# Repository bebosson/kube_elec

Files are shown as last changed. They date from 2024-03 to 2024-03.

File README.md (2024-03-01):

# Le Kube (School Electronic Project) 
Implementation of an IoT solution for growing plants.\
Development of the Bill of Materials (BOM), Specification Document, and PCB Fabrication. \
Electrical schematics, circuit design, and component soldering. \
Firmware development in C for Atmega328p and ESP328p microcontrollers, along with an Adafruit screen. \
Implementation of UART, SPI, and I2C protocols, AT command usage, EEPROM memory handling, timers, and interrupts. \
LAMP stack setup on Raspberry Pi with JavaScript and MySQL solutions. \
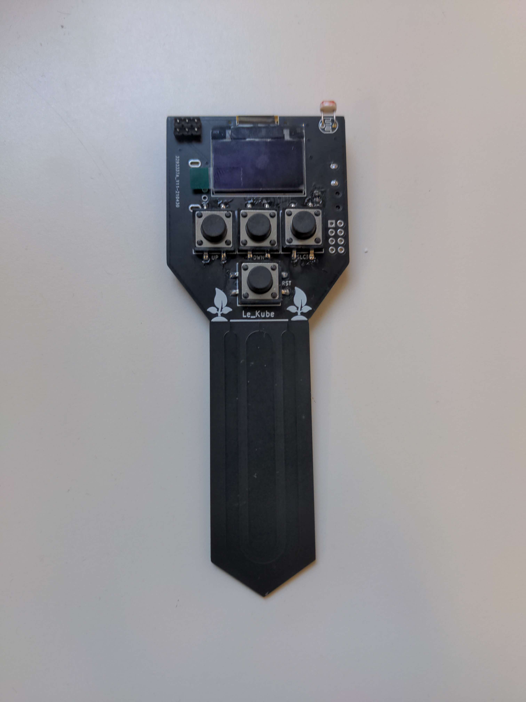
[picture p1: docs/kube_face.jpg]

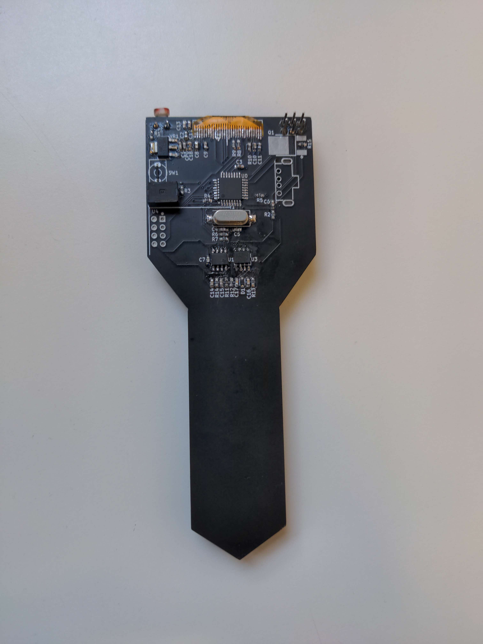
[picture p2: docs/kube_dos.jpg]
\
The data collected by the sensors are sent via wifi and accessible online, as well as on the Oled screen.
Variables monitored by the captors:
* `soil moisture
* `light
* `temperature
A water pump is connected to an optocoupler to automate the watering.

## Block diagram
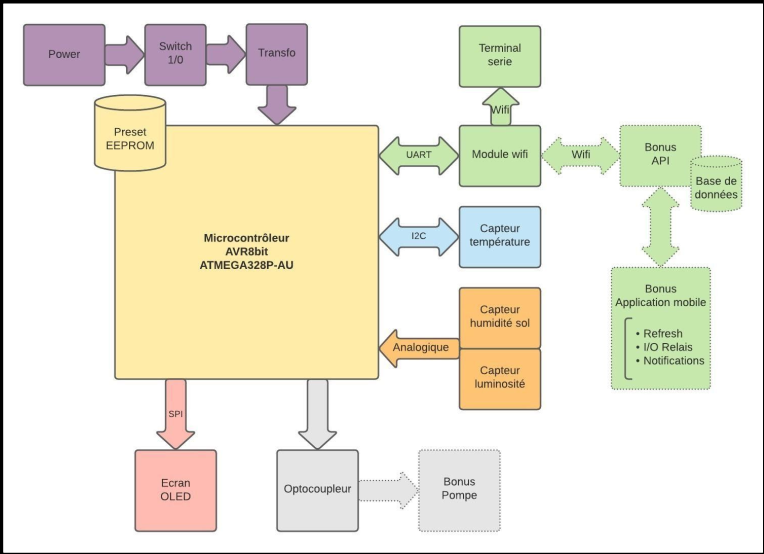
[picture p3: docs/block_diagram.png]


## Electric diagram
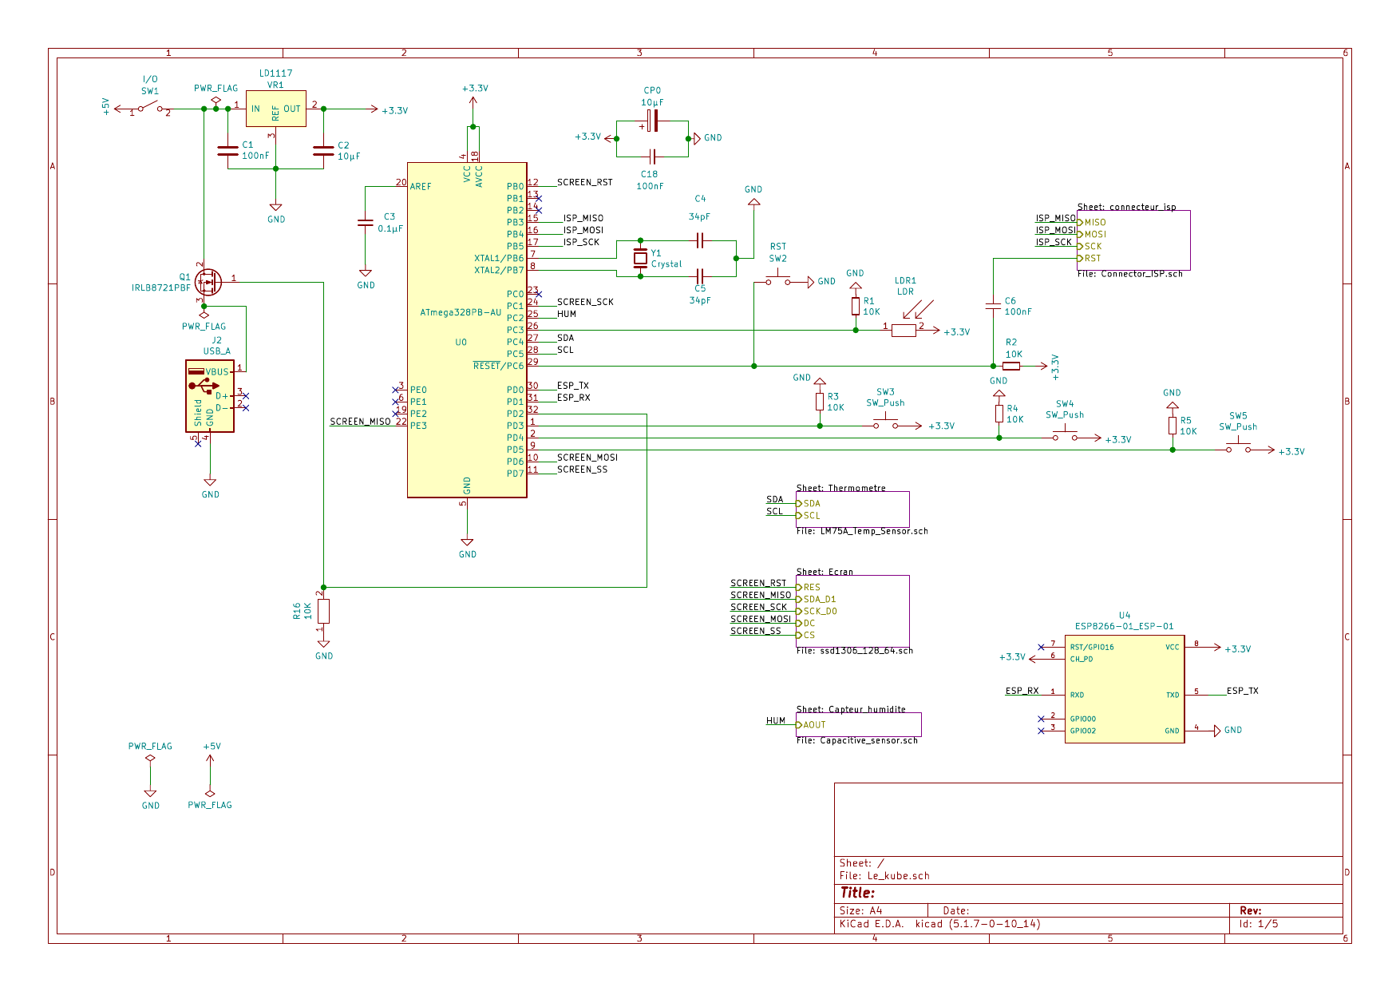
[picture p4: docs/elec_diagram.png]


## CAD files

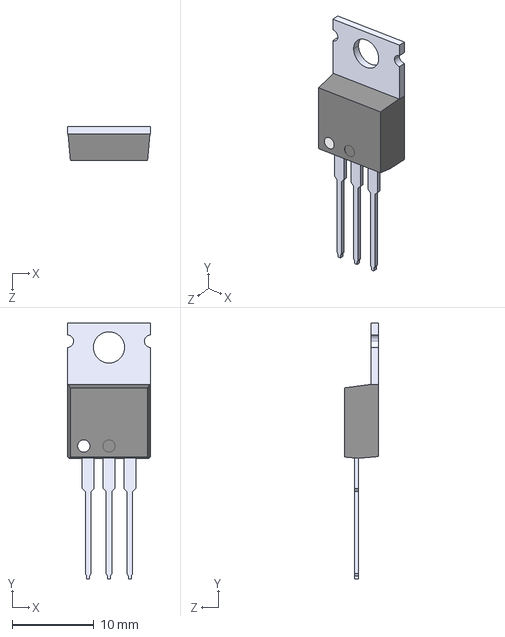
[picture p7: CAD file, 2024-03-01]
CAO/footprint/IRLB8721PBF/IRLB8721PBF.step
10.2 x 31.2 x 4.20 mm

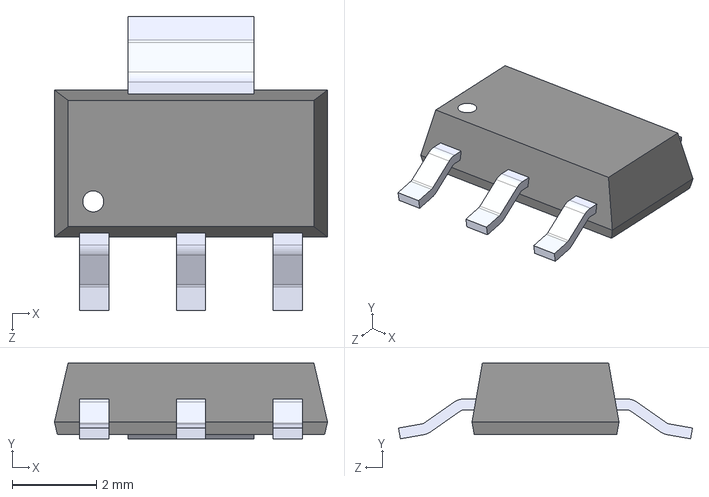
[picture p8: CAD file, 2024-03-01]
CAO/footprint/LD1117S33TR/LD1117S33TR.step
6.50 x 1.80 x 7.00 mm

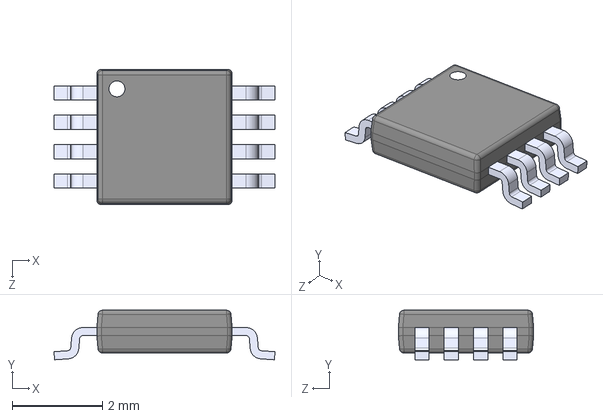
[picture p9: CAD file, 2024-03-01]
CAO/footprint/LM75AIMM_NOPB/LM75AIMM_NOPB.step
4.90 x 1.10 x 3.00 mm

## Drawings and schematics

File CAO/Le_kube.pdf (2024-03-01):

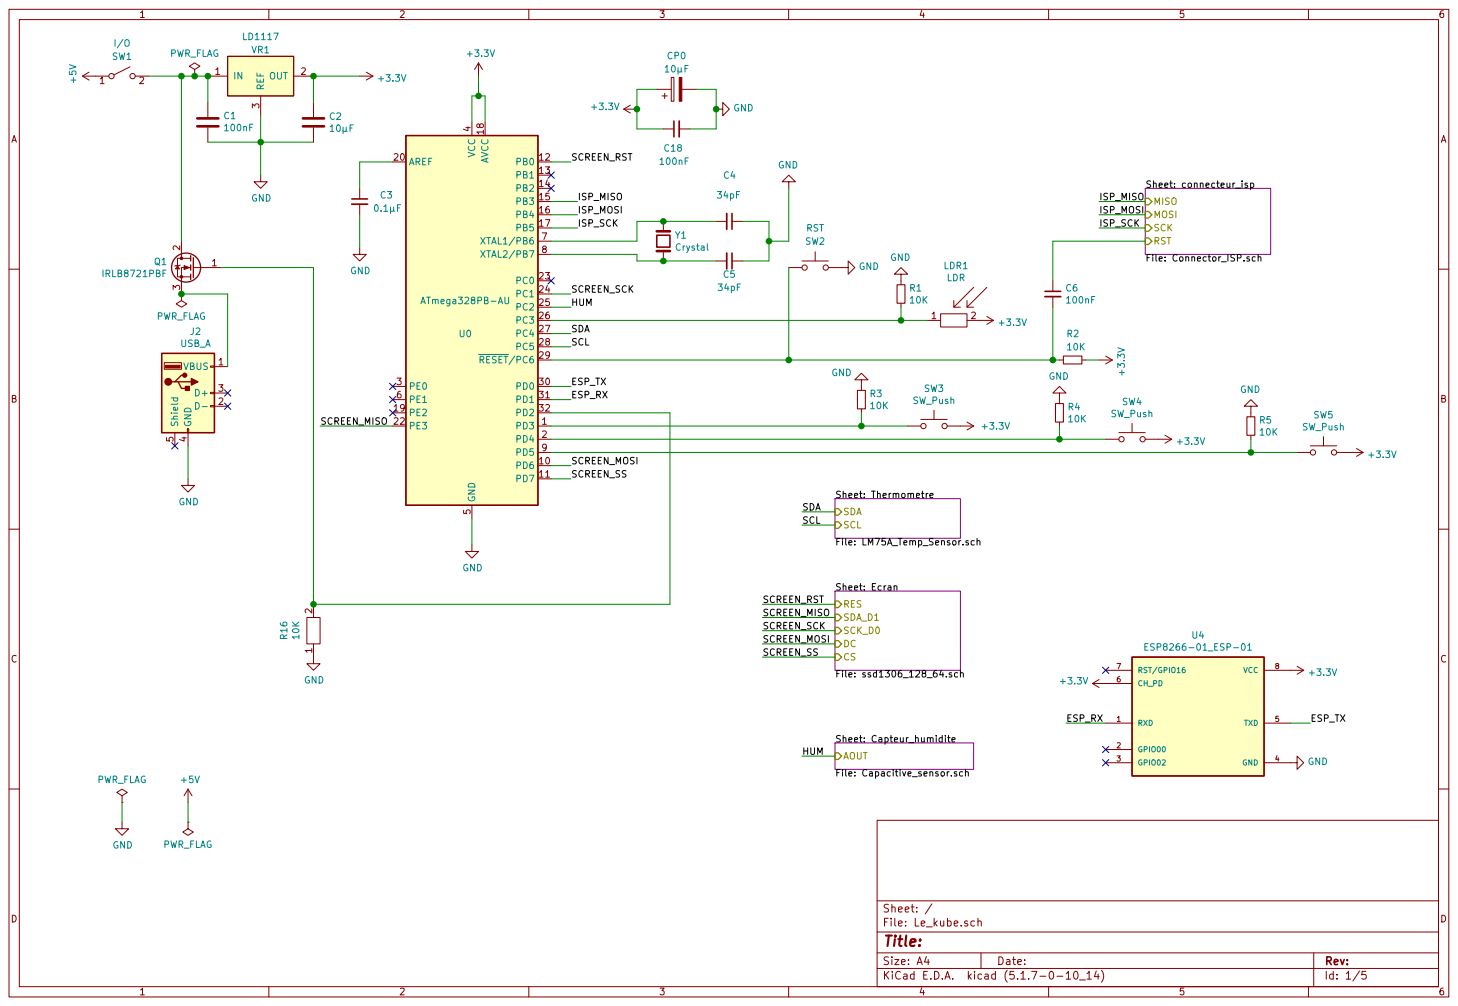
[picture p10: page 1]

Sheet: connecteur_isp File: Connector_ISP.sch MISO

SCK MOSI RST Sheet: Capteur_humidite

LDR1
File: Capacitive_sensor.sch AOUT Sheet: Thermometre File: LM75A_Temp_Sensor.sch SDA
SCREEN_MOSI SDA

SCL Sheet: Ecran File: ssd1306_128_64.sch CSDC

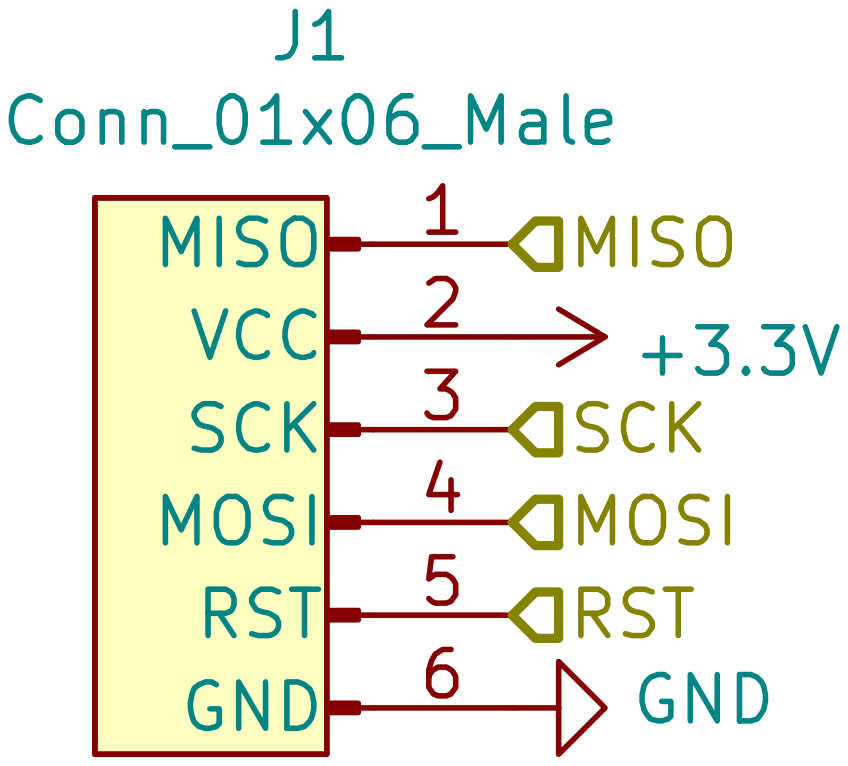
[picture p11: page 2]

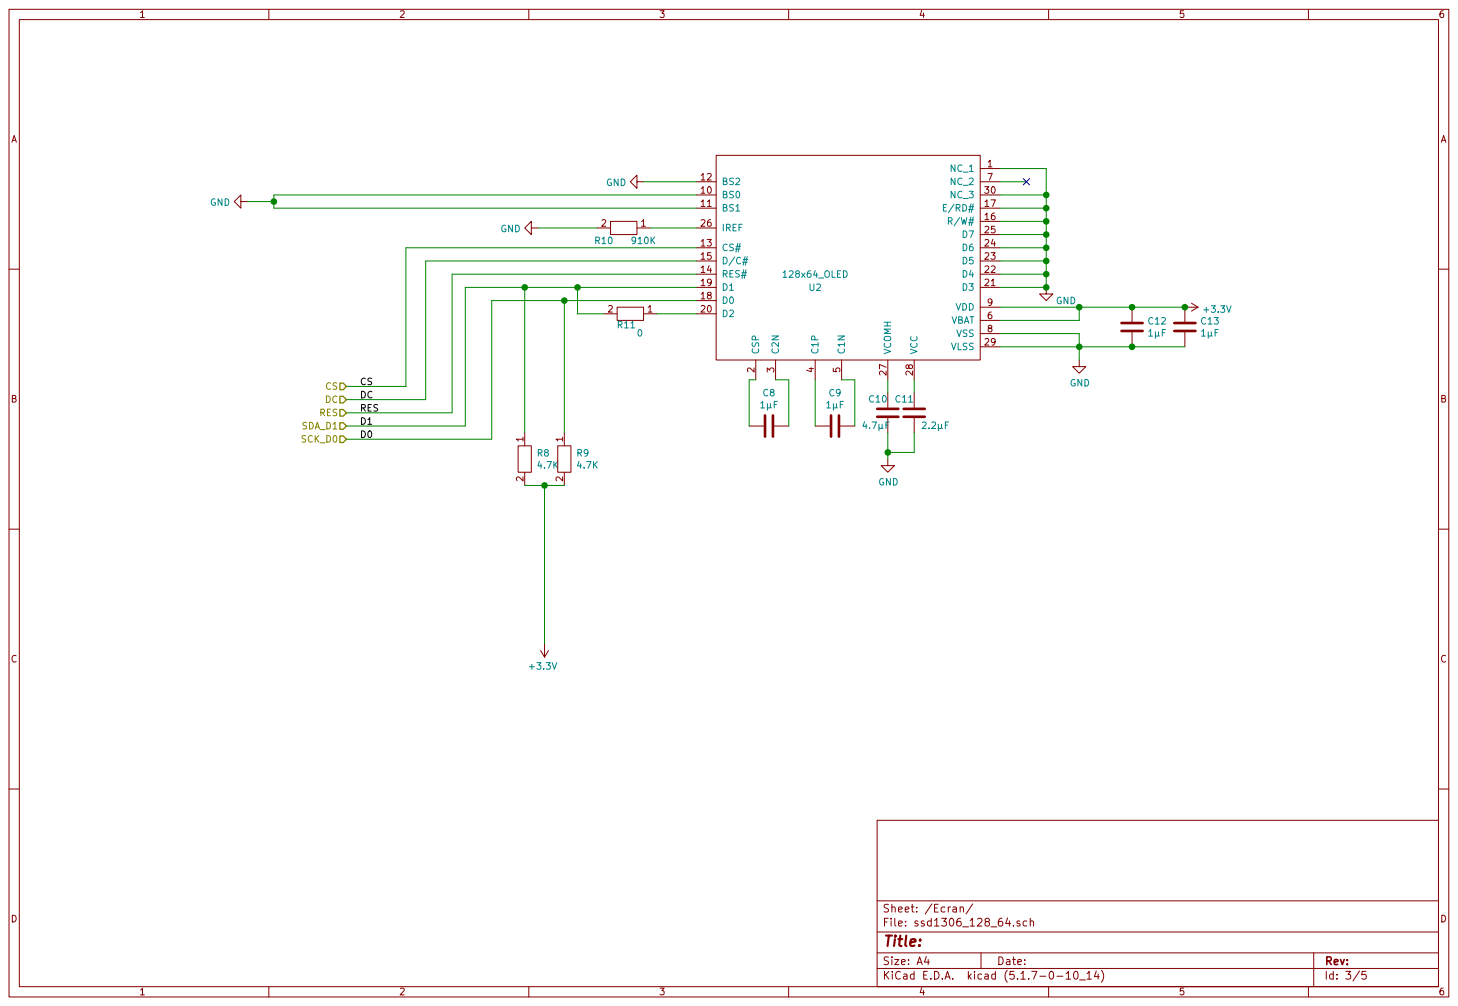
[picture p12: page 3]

File: ssd1306_128_64.sch Sheet: /Ecran/
Id: 3/5 Title:

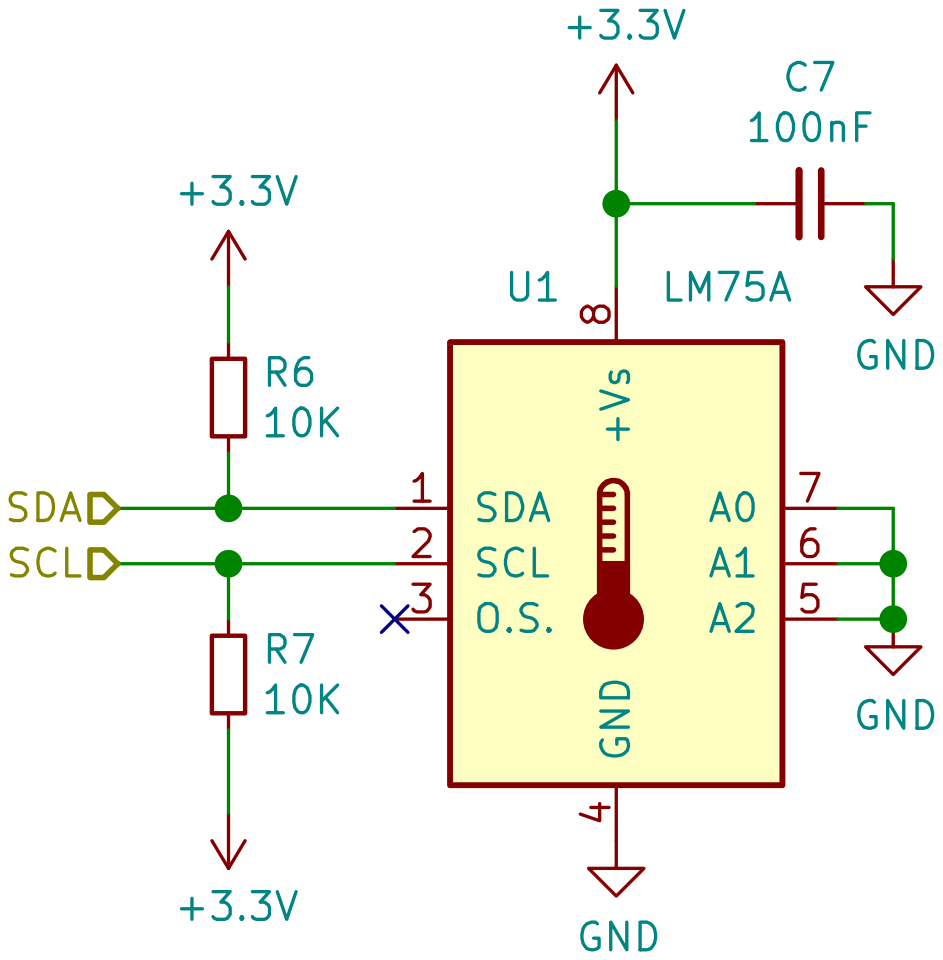
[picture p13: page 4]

File: LM75A_Temp_Sensor.sch Sheet: /Thermometre/
Id: 4/5 Title:

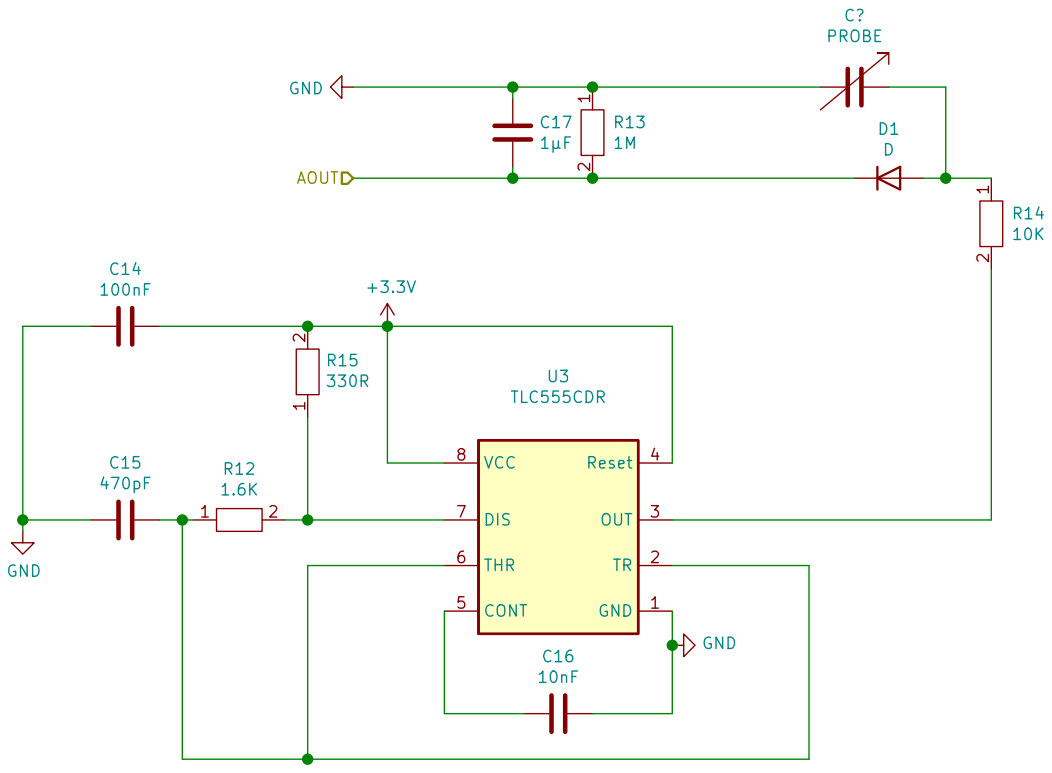
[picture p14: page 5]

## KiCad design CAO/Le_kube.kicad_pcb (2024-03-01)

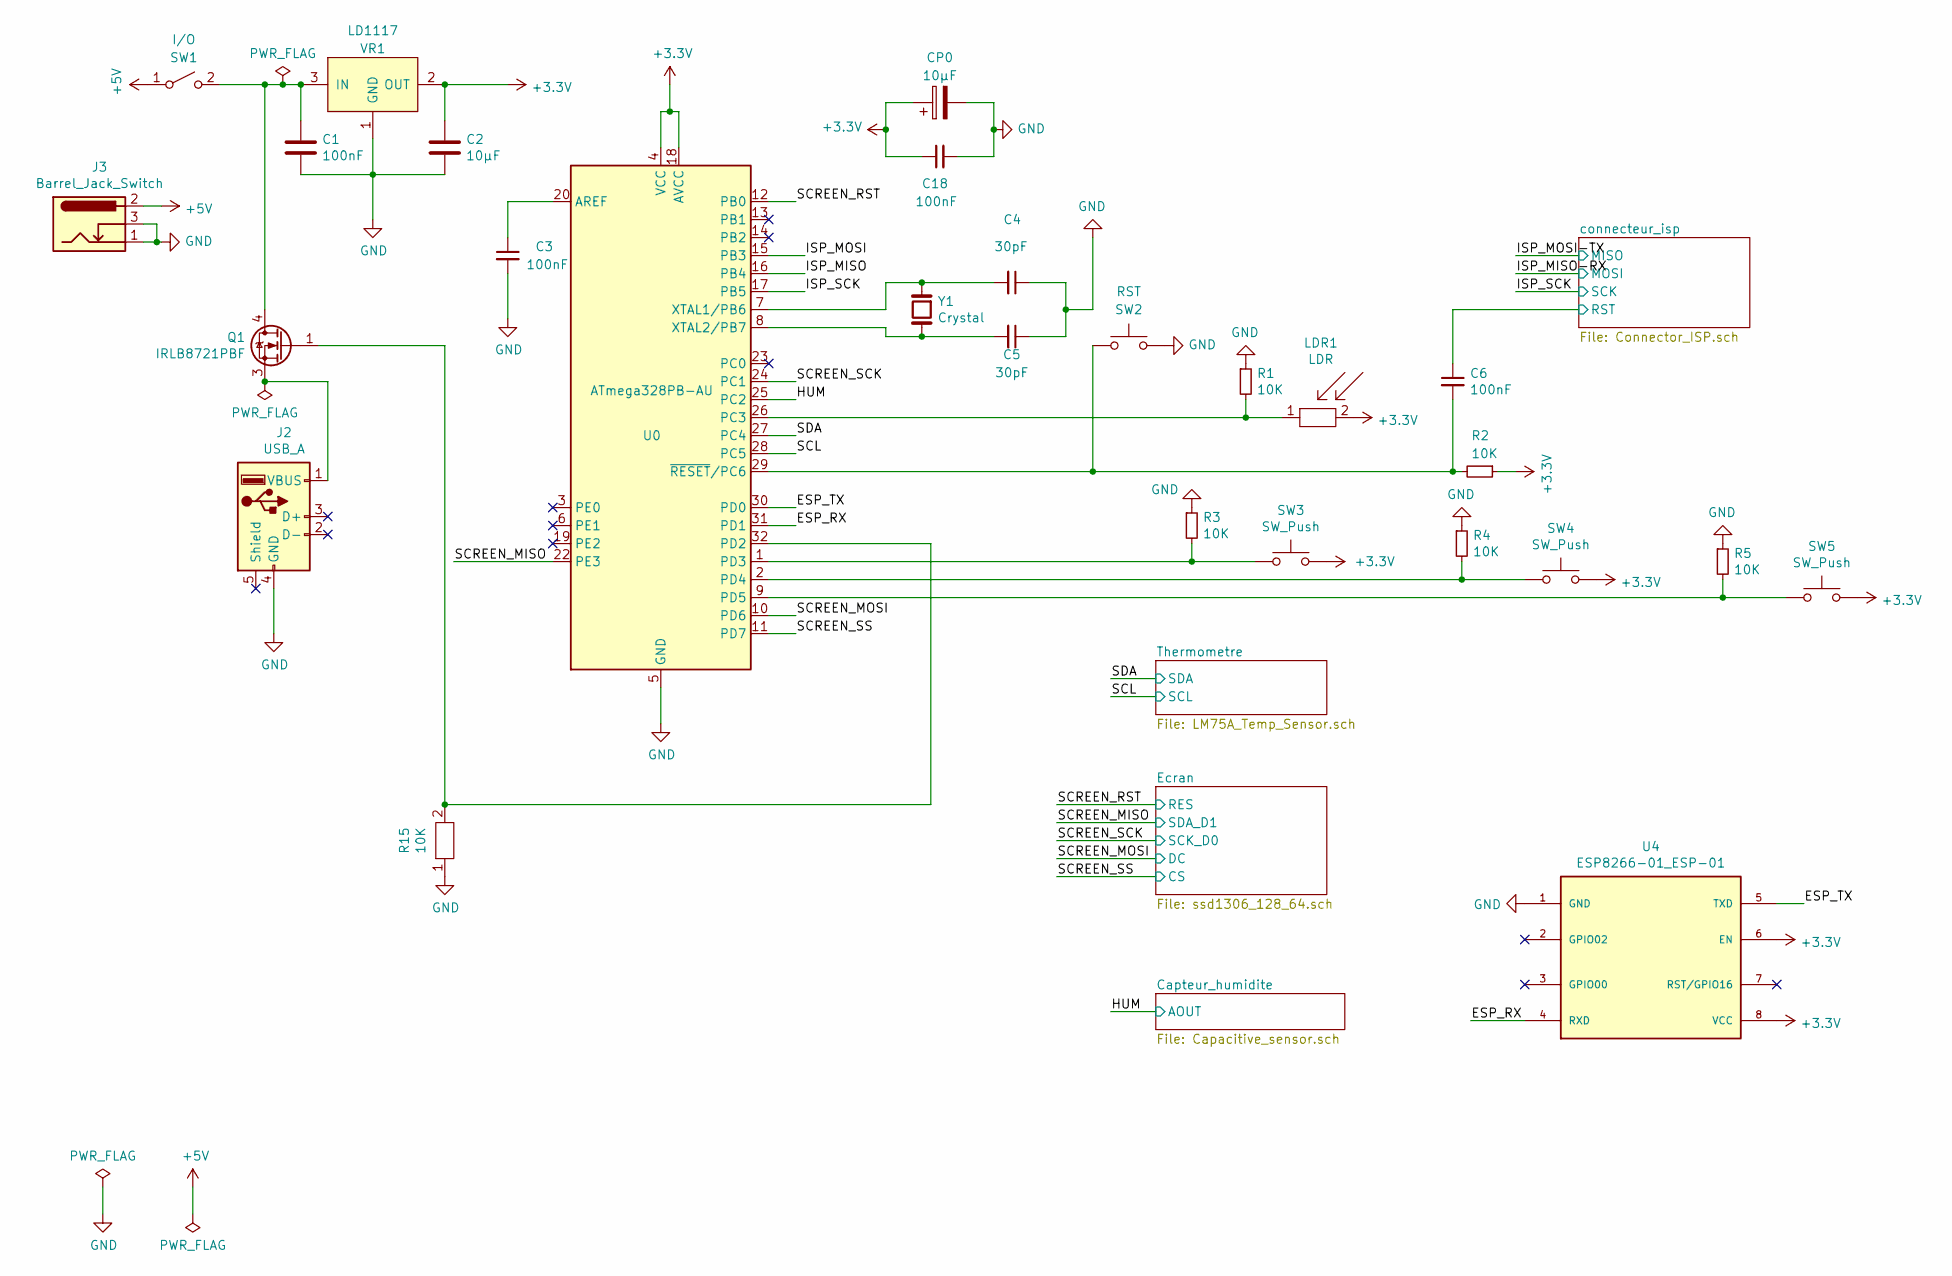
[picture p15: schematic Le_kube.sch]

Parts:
C1, C3, C6, C18: 100nF; C_0603_1608Metric_Pad1.08x0.95mm_HandSolder
C2: 10µF; C_0603_1608Metric_Pad1.08x0.95mm_HandSolder
C4, C5: 30pF; C_0603_1608Metric_Pad1.08x0.95mm_HandSolder
CP0: 10µF; C_0603_1608Metric_Pad1.08x0.95mm_HandSolder
J2: USB_A; USB-A-TH_USB-302-T
J3: Barrel_Jack_Switch; PORT-JACK(DC-IN-TH_DC-003-2A-1.3)
LDR1: LDR; LDR(RES-TH_L5.1-W4.3-P3.40-D0.5)
Q1: IRLB8721PBF; MOSFET(DPAK_L6.5-W6.0-P2.29-LS9.9-BR)
R1, R2, R3, R4, R5, R15: 10K; R_0603_1608Metric_Pad0.98x0.95mm_HandSolder
SW1: I/O; SW-TH_L8.0-W5.11-P5.08_TP11SH8CQE
SW2: RST; KEY-SMD_4P-L12.0-W12.0-P5.00-LS15.2
SW3, SW4, SW5: SW_Push; KEY-SMD_4P-L12.0-W12.0-P5.00-LS15.2
U0: ATmega328PB-AU; ATMEGA328PB-AU(TQFP-32_L7.0-W7.0-P0.80-LS9.0-BL)
U4: ESP8266-01_ESP-01; ESP-01S(WIFIM-TH_8P-L24.7-W14.4-P2.54)
VR1: LD1117; LD1117(SOT-223_L6.7-W3.5-P2.30-BR)
Y1: Crystal; Crystal(HC-49S_L11.4-W4.8)

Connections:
+3V3: C2.1, C18.1, CP0.1, LDR1.2, R2.1, SW3.4, SW4.4, SW5.4, U0.4 (VCC), U0.18 (AVCC), U4.6 (EN), U4.8 (VCC), VR1.2 (OUT); also elsewhere on the board
+5V: J3.2, SW1.1 (A)
/ESP_RX: U0.31 (PD1), U4.4 (RXD)
/ESP_TX: U0.30 (PD0), U4.5 (TXD)
/HUM: U0.25 (PC2); also elsewhere on the board
/ISP_MISO: U0.15 (PB3); also elsewhere on the board
/ISP_MOSI: U0.16 (PB4); also elsewhere on the board
/ISP_SCK: U0.17 (PB5); also elsewhere on the board
/SCL: U0.28 (PC5); also elsewhere on the board
/SCREEN_MISO: U0.22 (PE3); also elsewhere on the board
/SCREEN_MOSI: U0.10 (PD6); also elsewhere on the board
/SCREEN_RST: U0.12 (PB0); also elsewhere on the board
/SCREEN_SCK: U0.24 (PC1); also elsewhere on the board
/SCREEN_SS: U0.11 (PD7); also elsewhere on the board
/SDA: U0.27 (PC4); also elsewhere on the board
/connecteur_isp/RST: C6.1; also elsewhere on the board
GND: C1.1, C2.2, C3.2, C4.1, C5.1, C18.2, CP0.2, J2.4 (GND), J3.1, J3.3, R1.1, R3.1, R4.1, R5.1, R15.1, SW2.4, U0.5 (GND), U0.21 (GND), U4.1 (GND), VR1.1 (GND); also elsewhere on the board
unnamed: C1.2, Q1.4 (D), SW1.2 (B), VR1.3 (IN)
unnamed: C3.1, U0.20 (AREF)
unnamed: C4.2, U0.7 (XTAL1/PB6), Y1.1
unnamed: C5.2, U0.8 (XTAL2/PB7), Y1.2
unnamed: C6.2, R2.2, SW2.1, U0.29 (~RESET~/PC6)
unnamed: J2.1 (VBUS), Q1.3 (S)
unnamed: LDR1.1, R1.2, U0.26 (PC3)
unnamed: Q1.1 (G), R15.2, U0.32 (PD2)
unnamed: R3.2, SW3.1, U0.1 (PD3)
unnamed: R4.2, SW4.1, U0.2 (PD4)
unnamed: R5.2, SW5.1, U0.9 (PD5)

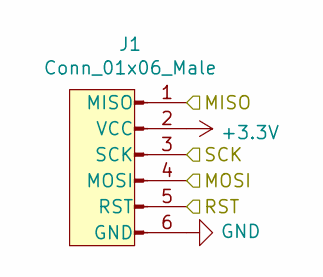
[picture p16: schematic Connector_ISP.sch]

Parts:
J1: Conn_01x06_Male; AVR-ISP(IDC-TH_6P-P2.54_C11214)

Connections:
+3V3: J1.2 (VCC); also elsewhere on the board
/ISP_MISO: J1.1 (MISO); also elsewhere on the board
/ISP_MOSI: J1.4 (MOSI); also elsewhere on the board
/ISP_SCK: J1.3 (SCK); also elsewhere on the board
/connecteur_isp/RST: J1.5 (RST); also elsewhere on the board
GND: J1.6 (GND); also elsewhere on the board

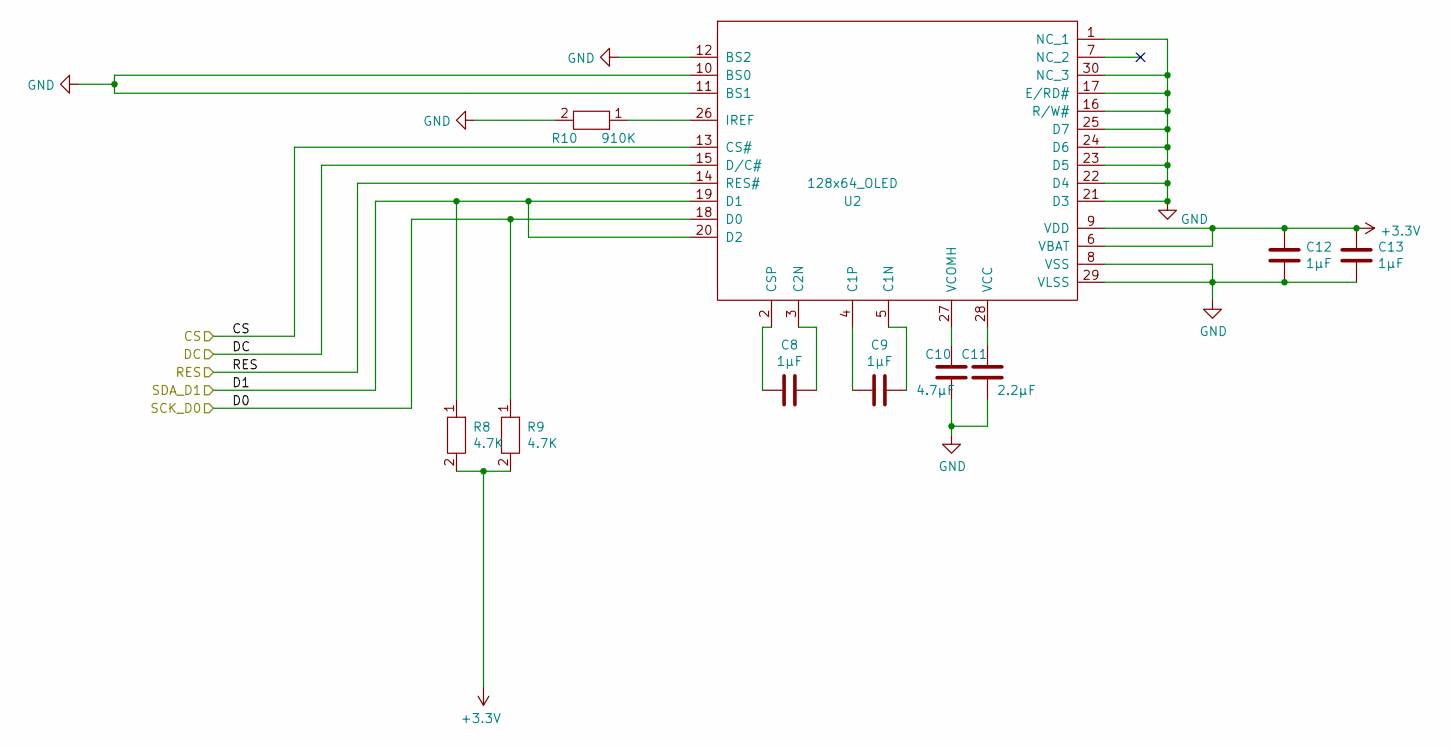
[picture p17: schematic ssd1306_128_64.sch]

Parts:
C8, C9, C12, C13: 1µF; C_0603_1608Metric_Pad1.08x0.95mm_HandSolder
C10: 4.7µF; C_0603_1608Metric_Pad1.08x0.95mm_HandSolder
C11: 2.2µF; C_0603_1608Metric_Pad1.08x0.95mm_HandSolder
R8, R9: 4.7K; R_0603_1608Metric_Pad0.98x0.95mm_HandSolder
R10: 910K; R_0603_1608Metric_Pad0.98x0.95mm_HandSolder
U2: 128x64_OLED; OLED-0.96-12864

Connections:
+3V3: C12.1, C13.1, R8.2, R9.2, U2.6 (VBAT), U2.9 (VDD); also elsewhere on the board
/SCREEN_MISO: R8.1, U2.19 (D1), U2.20 (D2); also elsewhere on the board
/SCREEN_MOSI: U2.15 (D/C#); also elsewhere on the board
/SCREEN_RST: U2.14 (RES#); also elsewhere on the board
/SCREEN_SCK: R9.1, U2.18 (D0); also elsewhere on the board
/SCREEN_SS: U2.13 (CS#); also elsewhere on the board
GND: C10.1, C11.1, C12.2, C13.2, R10.2, U2.1 (NC_1), U2.8 (VSS), U2.10 (BS0), U2.11 (BS1), U2.12 (BS2), U2.16 (R/W#), U2.17 (E/RD#), U2.21 (D3), U2.22 (D4), U2.23 (D5), U2.24 (D6), U2.25 (D7), U2.29 (VLSS), U2.30 (NC_3); also elsewhere on the board
unnamed: C8.1, U2.2 (CSP)
unnamed: C8.2, U2.3 (C2N)
unnamed: C9.1, U2.4 (C1P)
unnamed: C9.2, U2.5 (C1N)
unnamed: C10.2, U2.27 (VCOMH)
unnamed: C11.2, U2.28 (VCC)
unnamed: R10.1, U2.26 (IREF)

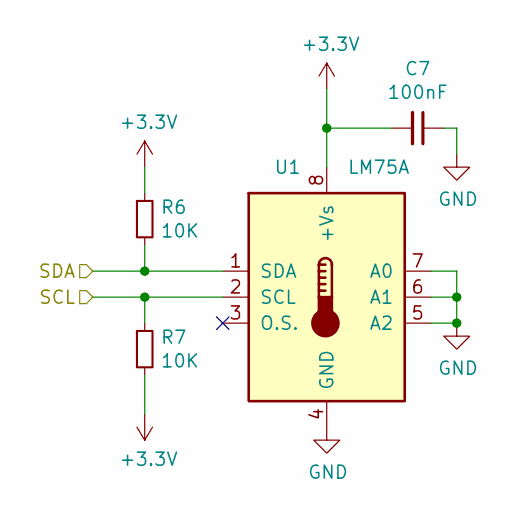
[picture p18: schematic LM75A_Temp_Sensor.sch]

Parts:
C7: 100nF; C_0603_1608Metric_Pad1.08x0.95mm_HandSolder
R6, R7: 10K; R_0603_1608Metric_Pad0.98x0.95mm_HandSolder
U1: LM75A; TEMP_SENSOR(SOIC-8_L5.0-W4.0-P1.27-LS6.0-BL)

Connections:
+3V3: C7.2, R6.1, R7.2, U1.8 (+Vs); also elsewhere on the board
/SCL: R7.1, U1.2 (SCL); also elsewhere on the board
/SDA: R6.2, U1.1 (SDA); also elsewhere on the board
GND: C7.1, U1.4 (GND), U1.5 (A2), U1.6 (A1), U1.7 (A0); also elsewhere on the board

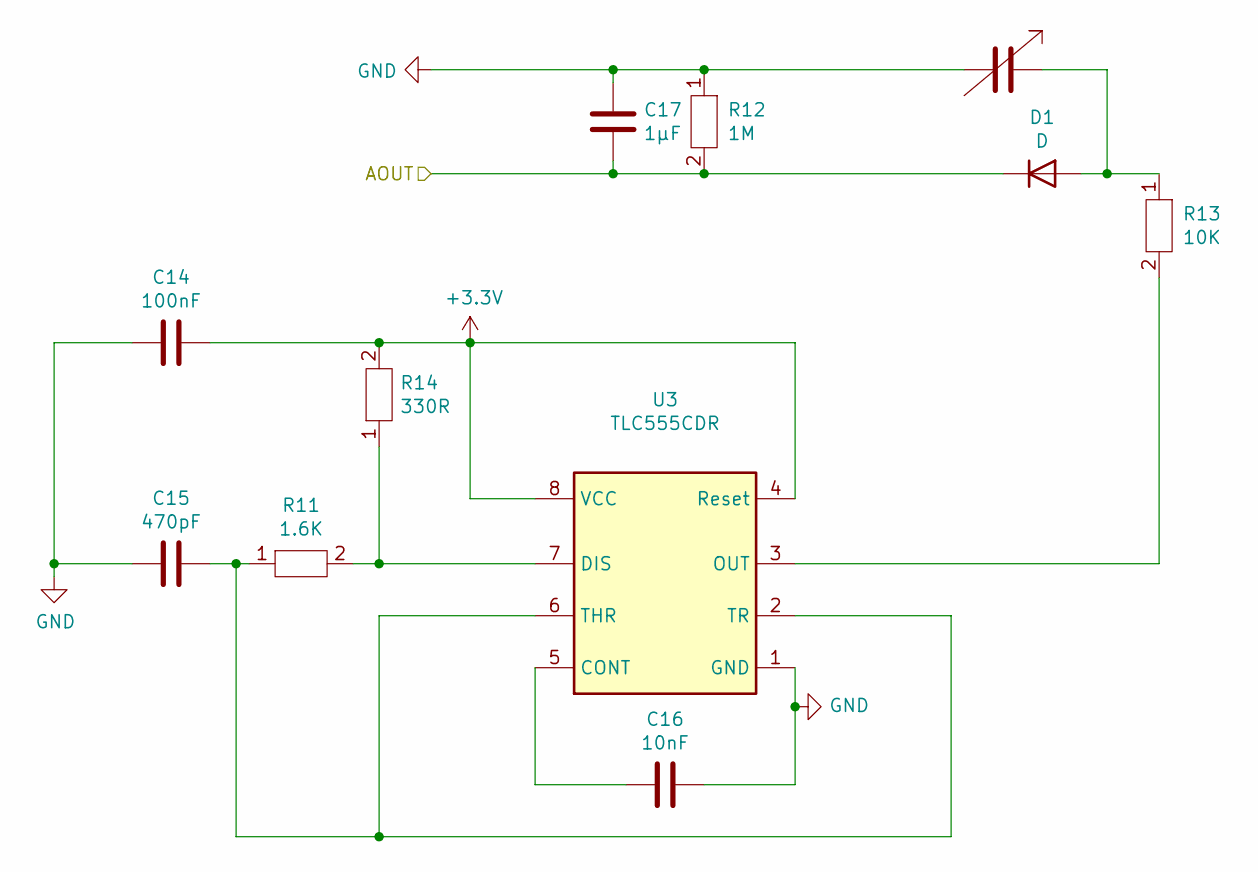
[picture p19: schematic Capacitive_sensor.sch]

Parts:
C14: 100nF; C_0603_1608Metric_Pad1.08x0.95mm_HandSolder
C15: 470pF; C_0603_1608Metric_Pad1.08x0.95mm_HandSolder
C16: 10nF; C_0603_1608Metric_Pad1.08x0.95mm_HandSolder
C17: 1µF; C_0603_1608Metric_Pad1.08x0.95mm_HandSolder
C19: PROBE
D1: D; SOD-323_L1.8-W1.3-LS2.5-RD
R11: 1.6K; R_0603_1608Metric_Pad0.98x0.95mm_HandSolder
R12: 1M; R_0603_1608Metric_Pad0.98x0.95mm_HandSolder
R13: 10K; R_0603_1608Metric_Pad0.98x0.95mm_HandSolder
R14: 330R; R_0603_1608Metric_Pad0.98x0.95mm_HandSolder
U3: TLC555CDR; TLC555(SOIC-8_L5.0-W4.0-P1.27-LS6.0-BL)

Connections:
+3V3: C14.2, R14.2, U3.4 (Reset), U3.8 (VCC); also elsewhere on the board
/HUM: C17.2, D1.1 (K), R12.2; also elsewhere on the board
GND: C14.1, C15.1, C16.2, C17.1, C19.1, R12.1, U3.1 (GND); also elsewhere on the board
unnamed: C15.2, R11.1, U3.2 (TR), U3.6 (THR)
unnamed: C16.1, U3.5 (CONT)
unnamed: C19.2, D1.2 (A), R13.1
unnamed: R11.2, R14.1, U3.7 (DIS)
unnamed: R13.2, U3.3 (OUT)

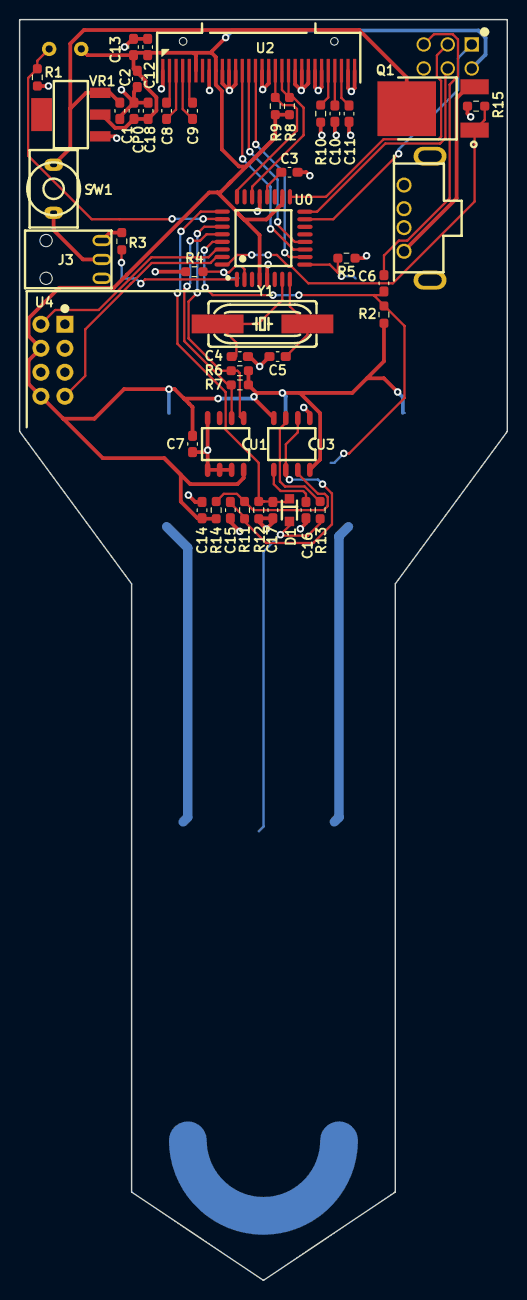
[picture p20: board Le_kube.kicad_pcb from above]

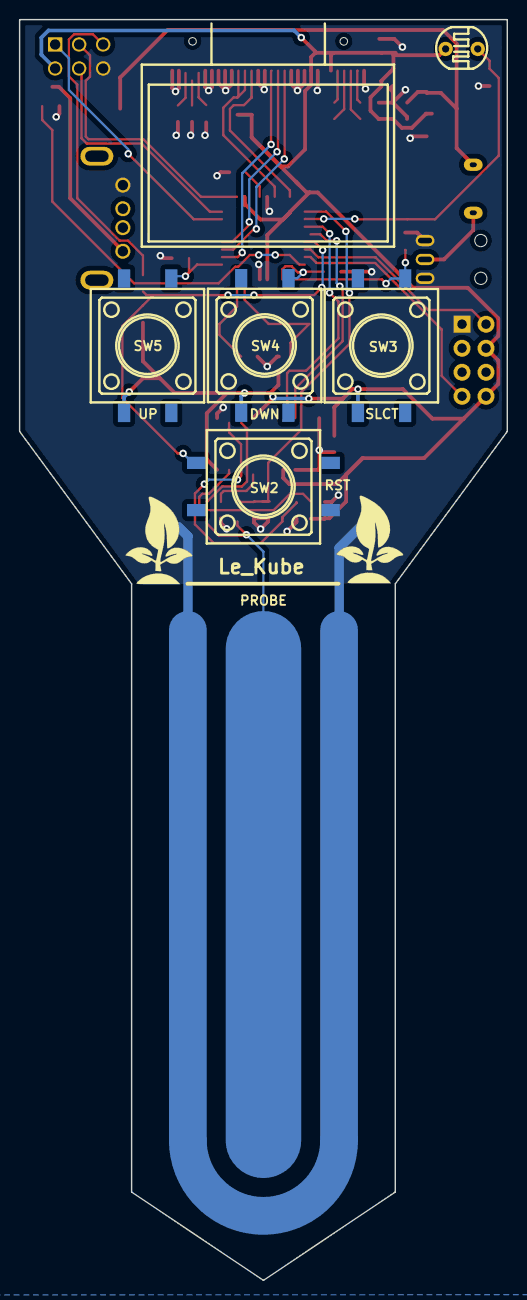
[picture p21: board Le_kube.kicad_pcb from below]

Board: 2 copper layers, 51.6 x 133.4 mm, 53 parts (6 on the bottom side), 40 nets.

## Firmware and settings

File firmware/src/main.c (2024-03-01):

#include "main.h"
#include <stdio.h>
#include <string.h>
#include <util/delay.h>

// extern uint8_t      font[50][6];
char water_pump = 0;
volatile uint8_t    chosen_specie; // =1 if a specie is chosen otherwise =0
volatile uint8_t    menuid = 1;
volatile uint8_t    btn_press = 0;

uint8_t   clean_transition()
{
    for (uint8_t i = 0; i < 8; i++)
        put_str("                    ", 0, i);
    return (1);
}

void    transition_menu(uint8_t *x, uint8_t *y)
{
    if (*x == 8)
        *x = 19;
    else if (*x == 19)
        *x = 8;
}



void   navigation_button(uint8_t *x, uint8_t *y)
{

    if (PIND & (1 << PD4)) //boutton du bas
    {
        put_str(" ",*x, *y);
        (*y)++;
        if (*y > 7)
        {
            transition_menu(x, y);
            *y = 3;
        }
        ft_delay(F_CPU / 500);
//        PIND ^= ~(1 << PD4); rebond ?
    }
    if (PIND & (1 << PD5)) // boutton du bas
    {
        put_str(" ",*x, *y);
        (*y)--;
        if (*y < 3)
        {
            transition_menu(x, y);
            *y = 7;
        }
//        PIND ^= ~(1 << PD5); rebond ?
        ft_delay(F_CPU / 500);
    }
}

void    render_menu()
{
    uint8_t spec[8];
    put_str("CHOISISSEZ VOTRE", 2, 0);
    put_str("ESPECE", 7, 1);
    eeprom_read_page(0, 8, spec);
    put_str((char *)spec,0,3);
    eeprom_read_page(18, 8, spec);
    put_str((char *)spec,0,4);
    // eeprom_read_page(18, 18, specie);
    // put_str(specie,0,4);
    // eeprom_read_page(36, 18, specie);
    // put_str(specie,0,5);
    // put_str("CHAMP 4   ",0,6);
    // put_str("CHAMP 5   ",0,7);
}

void    display_menu() //choix espece
{
    static uint8_t x = 8;
    static uint8_t y = 3;
    navigation_button(&x, &y);
    render_menu();
    put_str("<", x, y);
    // if (PIND & (1 << PORT3))
    // {
        // ft_delay(F_CPU / 1000);
        chosen_specie = (y - 2) + (x == 18 ? 5 : 0); // CHOOSE_SPECIES
        // return;
    // }
    print_screen();
    return ;
}



uint16_t  getTemperature() {

    uint8_t tx_address = DEFAULT_I2C_ADDRESS;
    uint8_t rx_data[TWI_BUFFER_LENGTH];

    uint8_t i = 0;
    while (i < TWI_BUFFER_LENGTH) {
        rx_data[i++] = 0;
    }
    twi_writeTo(tx_address, 0x00, 1, true, true); //get temperature
    twi_readFrom(tx_address, rx_data, 2, true); //receive temperature
    twi_writeTo(tx_address, 0, 0, true, true); //end of communication

    return ((uint16_t)rx_data[0] << 8) | (rx_data[1]);
}

void    print_temp(int16_t val, char *g_temp) {
    init_str(g_temp, 6);
    put_str("TEMPERATURE:         ", 0, 4);
    if (val < 0) {

        put_str("-", 13, 4);
        g_temp[0] = '-';
    }
    val &= ~(1 << 15); // clear neg bit
    putnbr(val >> 8, 14, 4);
    ft_uitoa(val >> 8, g_temp, 6);
    put_str(".", 15 + (val >> 8 >= 10) + (val >> 8 >= 100), 4);
    putnbr(125 * ((val >> 5) & 7) / 100, 16 + (val >> 8 >= 10) + (val >> 8 >= 100), 4);
    ft_uitoa(125 * ((val >> 5) & 7) / 100, append_str(g_temp, "."), 2);
    put_str("oC", 17 + (val >> 8 >= 10) + (val >> 8 >= 100), 4);
}

uint16_t read_lux() {
    uint16_t lux = 0;
    ADMUX &= ~(1 << MUX3);//set pin A3
    ADMUX &= ~(1 << MUX2);
    ADMUX |= (1 << MUX1);
    ADMUX |= (1 << MUX0);
    ADCSRA |= (1 << ADSC); // start calculations
        while((ADCSRA & (1 << ADSC))); // wait calculations is done
        lux = ADCL | (uint16_t)(ADCH & 0b11) << 8;
    
    return (lux);
}

uint16_t read_moisture(){
    uint16_t mois = 0;
    uint16_t v_sec = 896;
    uint16_t v_humide = 448;
    uint16_t diff = v_sec - v_humide;

    ADMUX |= (1 << MUX1); // set ADC2
    ADMUX &= ~(1 << MUX0);
    ADMUX &= ~(1 << MUX2);
    ADMUX &= ~(1 << MUX3);
    ADCSRA |= (1 << ADSC); // start calculations
    while((ADCSRA & (1 << ADSC))); // wait calculations is done
    mois = ADCL | (uint16_t)(ADCH & 0b11) << 8;
    mois = ( v_sec - mois ) * 100 / diff;
    water_pump = (mois < 25) ? 1 : 0; 

    // putnbr(adch, 0, 4);
    // print_screen();
    // return (mois);
    // return ((100 - ((mois * 100 / 1023) / 100)));
    // return (mois);
//    return ((1023 - mois) / 5);
      return (mois);
}

__attribute__ ((signal)) void INT1_vect()
{
    btn_press = 1;
}

void    display_info(char *g_lux, char *g_mois, char *g_temp)
{
    uint8_t     memory_species = 18 * (chosen_specie - 1);
    uint8_t     spec[8];
    uint16_t    lux;
    uint16_t    mois;

    lux = read_lux(g_lux);
    put_str("LUMINOSITE:         ", 0, 0);
    putnbr(lux, 13, 0);
    init_str(g_lux, 5);
    ft_uitoa(lux, g_lux, 5);
    mois = read_moisture();
    put_str("HUMIDITE:       % ", 0, 2);
    putnbr(mois, 13, 2);
    init_str(g_mois, 5);
    ft_uitoa(mois, g_mois, 5);
    print_temp(getTemperature(), g_temp);
    put_str("ESPECE:   ", 0, 6);
    eeprom_read_page(memory_species, 8, spec); // recuperer dans la memoire l'espece choisi
    put_str((char *)spec, 11, 6);
    print_screen();
}


int       main() {
    uint16_t cptr = 0;
    char g_lux[5] = "\0\0\0\0";
    char g_mois[5] = "\0\0\0\0";
    char g_temp[6] = "\0\0\0\0\0";
    EICRA |= (1 << ISC10) | (1 << ISC11);
    SREG |= 1 << SREG_I; //allows interrupt
    EIMSK |= (1 << INT1); //enable INT1 for Select button press
    ADCSRA |= (1 << ADEN); // enable ADC
    ADMUX |= (1 << REFS0); // AVCC with external capacitor at AREF pin
    DDRD |= (1 << PD2); // POMPE
    PORTD |= (1 << PD2);
    ft_delay(F_CPU / 50);
    display_init(); //pin connected to screen
    // eeprom_write_specie();
    uart_init();
    ft_delay(F_CPU / 50);
    while(1) {
        if (btn_press) {
            clear_buffer();
            menuid = !menuid;
            _delay_ms(150);
            btn_press = 0;
        }
        if (menuid == 1)
            display_menu();
        else {
            display_info(g_lux, g_mois, g_temp);
            if (cptr++ == 1800) {
                put_str("SENDING!", 0, 7);
                print_screen();
                esp_send_data(g_lux, g_temp, g_mois);
                put_str("SENT!   ", 0, 7);
                print_screen();
                cptr = 0;
            }
        }
        ft_delay(F_CPU / 1000); 
    }
    return 0;
}

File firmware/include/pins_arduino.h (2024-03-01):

/*
  pins_arduino.h - Pin definition functions for Arduino
  Part of Arduino - http://www.arduino.cc/
  Copyright (c) 2007 David A. Mellis
  This library is free software; you can redistribute it and/or
  modify it under the terms of the GNU Lesser General Public
  License as published by the Free Software Foundation; either
  version 2.1 of the License, or (at your option) any later version.
  This library is distributed in the hope that it will be useful,
  but WITHOUT ANY WARRANTY; without even the implied warranty of
  MERCHANTABILITY or FITNESS FOR A PARTICULAR PURPOSE.  See the GNU
  Lesser General Public License for more details.
  You should have received a copy of the GNU Lesser General
  Public License along with this library; if not, write to the
  Free Software Foundation, Inc., 59 Temple Place, Suite 330,
  Boston, MA  02111-1307  USA
*/

#ifndef Pins_Arduino_h
#define Pins_Arduino_h

// #include "avr/pgmspace.h"

#define NUM_DIGITAL_PINS            20
#define NUM_ANALOG_INPUTS           6
#define analogInputToDigitalPin(p)  ((p < 6) ? (p) + 14 : -1)

#if defined(__AVR_ATmega8__)
#define digitalPinHasPWM(p)         ((p) == 9 || (p) == 10 || (p) == 11)
#else
#define digitalPinHasPWM(p)         ((p) == 3 || (p) == 5 || (p) == 6 || (p) == 9 || (p) == 10 || (p) == 11)
#endif

#define PIN_SPI_SS    (10)
#define PIN_SPI_MOSI  (11)
#define PIN_SPI_MISO  (12)
#define PIN_SPI_SCK   (13)

static const uint8_t SS   = PIN_SPI_SS;
static const uint8_t MOSI = PIN_SPI_MOSI;
static const uint8_t MISO = PIN_SPI_MISO;
static const uint8_t SCK  = PIN_SPI_SCK;

#define PIN_WIRE_SDA        (18)
#define PIN_WIRE_SCL        (19)

static const uint8_t SDA = PIN_WIRE_SDA;
static const uint8_t SCL = PIN_WIRE_SCL;

#define LED_BUILTIN 13

#define PIN_A0   (14)
#define PIN_A1   (15)
#define PIN_A2   (16)
#define PIN_A3   (17)
#define PIN_A4   (18)
#define PIN_A5   (19)
#define PIN_A6   (20)
#define PIN_A7   (21)

static const uint8_t A0 = PIN_A0;
static const uint8_t A1 = PIN_A1;
static const uint8_t A2 = PIN_A2;
static const uint8_t A3 = PIN_A3;
static const uint8_t A4 = PIN_A4;
static const uint8_t A5 = PIN_A5;
static const uint8_t A6 = PIN_A6;
static const uint8_t A7 = PIN_A7;

#define digitalPinToPCICR(p)    (((p) >= 0 && (p) <= 21) ? (&PCICR) : ((uint8_t *)0))
#define digitalPinToPCICRbit(p) (((p) <= 7) ? 2 : (((p) <= 13) ? 0 : 1))
#define digitalPinToPCMSK(p)    (((p) <= 7) ? (&PCMSK2) : (((p) <= 13) ? (&PCMSK0) : (((p) <= 21) ? (&PCMSK1) : ((uint8_t *)0))))
#define digitalPinToPCMSKbit(p) (((p) <= 7) ? (p) : (((p) <= 13) ? ((p) - 8) : ((p) - 14)))

#define digitalPinToInterrupt(p)  ((p) == 2 ? 0 : ((p) == 3 ? 1 : NOT_AN_INTERRUPT))

// #ifdef ARDUINO_MAIN

// // On the Arduino board, digital pins are also used
// // for the analog output (software PWM).  Analog input
// // pins are a separate set.

// // ATMEL ATMEGA8 & 168 / ARDUINO
// //
// //                  +-\/-+
// //            PC6  1|    |28  PC5 (AI 5)
// //      (D 0) PD0  2|    |27  PC4 (AI 4)
// //      (D 1) PD1  3|    |26  PC3 (AI 3)
// //      (D 2) PD2  4|    |25  PC2 (AI 2)
// // PWM+ (D 3) PD3  5|    |24  PC1 (AI 1)
// //      (D 4) PD4  6|    |23  PC0 (AI 0)
// //            VCC  7|    |22  GND
// //            GND  8|    |21  AREF
// //            PB6  9|    |20  AVCC
// //            PB7 10|    |19  PB5 (D 13)
// // PWM+ (D 5) PD5 11|    |18  PB4 (D 12)
// // PWM+ (D 6) PD6 12|    |17  PB3 (D 11) PWM
// //      (D 7) PD7 13|    |16  PB2 (D 10) PWM
// //      (D 8) PB0 14|    |15  PB1 (D 9) PWM
// //                  +----+
// //
// // (PWM+ indicates the additional PWM pins on the ATmega168.)

// // ATMEL ATMEGA1280 / ARDUINO
// //
// // 0-7 PE0-PE7   works
// // 8-13 PB0-PB5  works
// // 14-21 PA0-PA7 works 
// // 22-29 PH0-PH7 works
// // 30-35 PG5-PG0 works
// // 36-43 PC7-PC0 works
// // 44-51 PJ7-PJ0 works
// // 52-59 PL7-PL0 works
// // 60-67 PD7-PD0 works
// // A0-A7 PF0-PF7
// // A8-A15 PK0-PK7


// // these arrays map port names (e.g. port B) to the
// // appropriate addresses for various functions (e.g. reading
// // and writing)
// const uint16_t PROGMEM port_to_mode_PGM[] = {
// 	NOT_A_PORT,
// 	NOT_A_PORT,
// 	(uint16_t) &DDRB,
// 	(uint16_t) &DDRC,
// 	(uint16_t) &DDRD,
// };

// const uint16_t PROGMEM port_to_output_PGM[] = {
// 	NOT_A_PORT,
// 	NOT_A_PORT,
// 	(uint16_t) &PORTB,
// 	(uint16_t) &PORTC,
// 	(uint16_t) &PORTD,
// };

// const uint16_t PROGMEM port_to_input_PGM[] = {
// 	NOT_A_PORT,
// 	NOT_A_PORT,
// 	(uint16_t) &PINB,
// 	(uint16_t) &PINC,
// 	(uint16_t) &PIND,
// };

// const uint8_t PROGMEM digital_pin_to_port_PGM[] = {
// 	PD, /* 0 */
// 	PD,
// 	PD,
// 	PD,
// 	PD,
// 	PD,
// 	PD,
// 	PD,
// 	PB, /* 8 */
// 	PB,
// 	PB,
// 	PB,
// 	PB,
// 	PB,
// 	PC, /* 14 */
// 	PC,
// 	PC,
// 	PC,
// 	PC,
// 	PC,
// };
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

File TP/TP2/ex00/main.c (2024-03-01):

#include <avr/io.h>

int main(void)
{
    DDRD &= ~(1 << DDD3);     // Clear the PD2 pin
    // PD2 (PCINT0 pin) is now an input

    PORTD |= (1 << PORTD2);    // turn On the Pull-up
    // PD2 is now an input with pull-up enabled



    EICRA |= (1 << ISC01);    // set INT0 to trigger on ANY logic change
    EIMSK |= (1 << INT1);     // Turns on INT0


    while(1)
    {
        /*main program loop here */
    }
}



ISR (INT0_vect)
{
    /* interrupt code here */
}
